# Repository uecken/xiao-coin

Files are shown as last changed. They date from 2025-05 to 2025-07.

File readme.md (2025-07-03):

# XIAO-Coin で始めるIoT開発

詳細ガイドブック：

📖 **[XIAO-Coin ガイドブック](xiao_coin_ebook.md)**

電源スイッチの代替は下記などをご利用ください。

 - 小型スライドスイッチ 1回路2接点 SS12D01G4
https://akizukidenshi.com/catalog/g/g112723/

- スライドスイッチ 1回路2接点 基板用 横向き
https://akizukidenshi.com/catalog/g/g115704/

---

JLCPCBで発注する際は全て通常設定です。
Castellated HolesをYesにすると綺麗にカットしてもらえますが、エッジでしか使えないようなのと費用が嵩むためNoとします。
また、今回は基板の内枠を切り取っているため恐らく使えません。



**販売サイト**: [スイッチサイエンス](https://www.switch-science.com/products/10032)

**GitHub**: [https://github.com/uecken/xiao-coin](https://github.com/uecken/xiao-coin)

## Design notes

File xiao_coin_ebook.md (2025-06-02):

---
pdf-engine: xelatex
CJKmainfont: "Noto Serif CJK JP"
papersize: b5paper
geometry: 
  - paper=b5paper
  - margin=2cm
  - paperwidth=176mm
  - paperheight=250mm
top-level-division: chapter #見出し毎に改ページ
numbersections: false
figureTitle: ""
tableTitle: ""
listingTitle: ""
figPrefix: ""
eqnPrefix: ""
tblPrefix: ""
lstPrefix: ""
header-includes:
  - \usepackage{caption}
  - \captionsetup{labelformat=empty}
  - \captionsetup[figure]{labelformat=empty}
---

<div style="text-align: center; page-break-after: always;">

<br><br>

::: {=latex}
\centering
\Huge \textbf{XIAO-Coinで始めるIoT}
\vspace{4cm}
:::

<br><br>

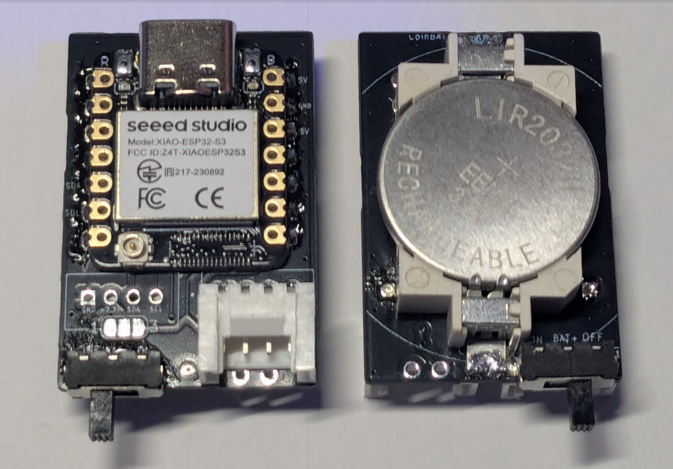
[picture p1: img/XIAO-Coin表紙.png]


<br><br>

::: {=latex}
\centering
\Large \textbf{やわらからじお}

\normalsize
\raggedright
:::

</div>

::: {=latex}
\newpage
:::

------------------------------------------------------------------------

目次
----

1.  [はじめに](#はじめに)
2.  [XIAO-Coinについて](#xiao-coinについて)
3.  [部品とコスト](#部品とコスト)
4.  [組み立て手順](#組み立て手順)
5.  [開発環境の構築](#開発環境の構築)
6.  [センサー接続とプログラミング](#センサー接続とプログラミング)
7.  [応用例とプロジェクト](#応用例とプロジェクト)
8.  [トラブルシューティング](#トラブルシューティング)
9.  [接続図とPCB](#接続図とPCB)
10. [参考資料](#参考資料)

はじめに
--------

本書は、XIAO-Coinを使用した小型充電式無線マイコン、並びにMicroPythonによる簡易なプログラミング解説するガイドブックです。

### 対象読者

-   電子工作初心者ー中級者
-   小型デバイスでのプロトタイピングを行いたい方

### 本書で学べること

-   XIAO-Coinの組み立て
-   MicroPythonによるプログラミング -各種センサーの活用方法

#### 注意点

  - **CR2032電池は使用できません** 
  - **一般的なリチウム電池は使用できません** 
  - **LIR2032/2450専用です**（リチウムイオンコイン電池のみ） 
  - **半田付けに慣れている必要があります**

::: {=latex}
\newpage
:::

XIAO-Coinについて
---------------------

### 概要

XIAO-Coinは、リチウムイオン充電機能のあるSeeed Studio製XIAOとリチウムイオンコイン電池を組み合わせた、小型（38mm x 28mm）の無線マイコンボードです。

オンラインで基板セットを販売しています。GitHubでKiCADファイルを公開していますので、気に入った方は沢山創ったり、カスタマイズして是非ご利用ください。

**スイッチサイエンス販売サイト**: <https://www.switch-science.com/products/10032>

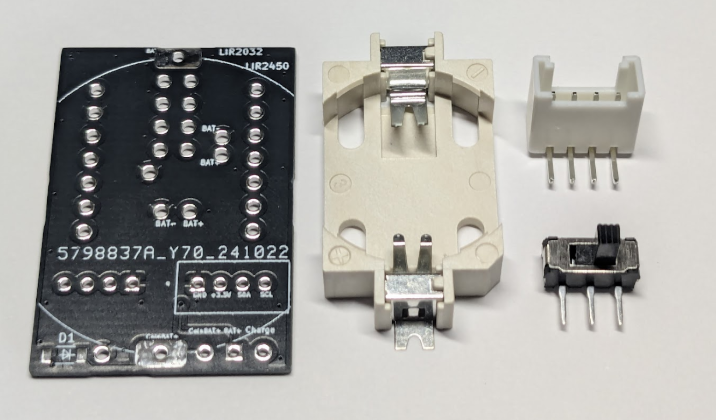
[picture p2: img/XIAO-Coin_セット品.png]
XIAO-Coin_セット品


### 特徴

-   XIAOの小ささとLipo充電端子を生かしたコインホルダー一体型無線マイコン
-   Grove端子でI2Cセンサ接続可能
-   充電機能内蔵のため各種コイン電池に対応：45mAh〜120mAh（2032〜2450サイズ）

::: {=latex}
\newpage
:::

必要部品とコスト
----------------

### 必要部品一覧（BOM）

- XIAOの単価はC3が最も安く、630円/個で試作できるため各種センサの動作評価に向いています。
- これだけ安ければ動作したセンサとセットでそのままにしておけるので、毎回ソフトやセンサを付け替える必要が無いのが便利です。

| 名称 | 価格 | 販売先 | 備考 |
|---|---|---|---|
| XIAO ESP32 C3/C6/S3 | 630円〜810円 | Seeed | 10個購入時の値段  |
| ボタン電池基板取付用ホルダー CH29-2032LF | 50円 | 秋月電子 |
| スライドスイッチ MK-12D13G4-B | 10円 | LCSC | 
| Groveコネクター L型 スルーホール | 15円 | 秋月電子 | 

電源スイッチは背丈の小さいものを採用していますが、秋月電子で代替できる部品は下記です。
 - 小型スライドスイッチ 1回路2接点 SS12D01G4
https://akizukidenshi.com/catalog/g/g112723/
- スライドスイッチ 1回路2接点 基板用 横向き
https://akizukidenshi.com/catalog/g/g115704/

### XIAO各種モデルの単価（Seeed社から10個購入時）

| モデル | 単価（USD） | 単価（円）* | 特徴 |
|---|---|---|---|
| XIAO ESP32 C3 | $4.20 | 630円 | 最安価、WiFi/Bluetooth対応 |
| XIAO ESP32 C6 | $4.90 | 735円 | WiFi 6対応、Thread/Zigbee対応 |
| XIAO ESP32 S3 | $5.40 | 810円 | カメラ対応、AI機能強化 |

*為替レート: 1USD = 150円で計算

### 推奨電池

EEMB LIR2032H 充電式バッテリー - 電圧: 3.7V - 容量: 70mAh - 価格:
¥1,309

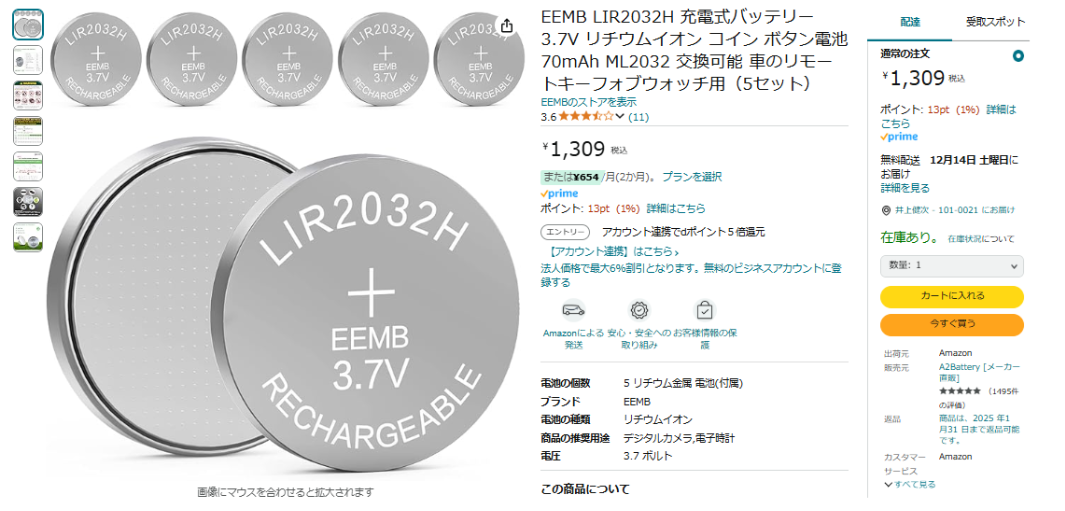
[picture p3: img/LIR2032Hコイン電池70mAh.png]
LIR2032H電池


::: {=latex}
\newpage
:::

組み立て手順
------------

## 部品のハンダ付け手順

1. 基板にXIAOを半田付け
2. 裏面の充電端子をホール半田付け
3. 電源スイッチを半田付け
4. Grove端子を半田付け
5. バッテリーホルダーを半田付け

注: 先にバッテリーホルダーを付けると、XIAOの充電端子を半田付けできないので注意。
次ページで写真付きで説明します。

## XIAOと基板の半田付け
  - XIAOの片側の端子をピン固定し、反対側の端子を半田付けする。

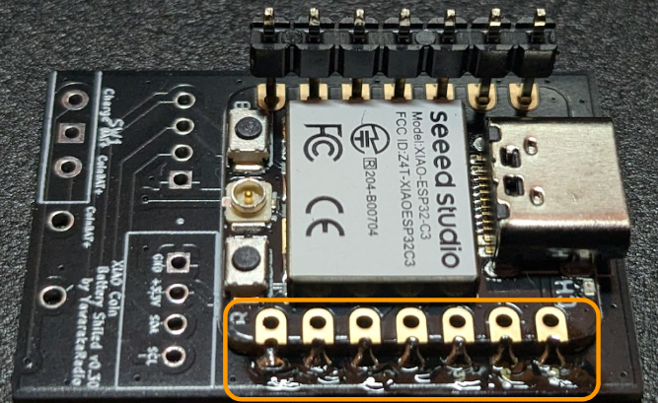
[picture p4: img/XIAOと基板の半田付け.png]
XIAOと基板の半田付け


## XIAOのはんだ付け
  - 反対側のピンを外し、はんだ付けする。

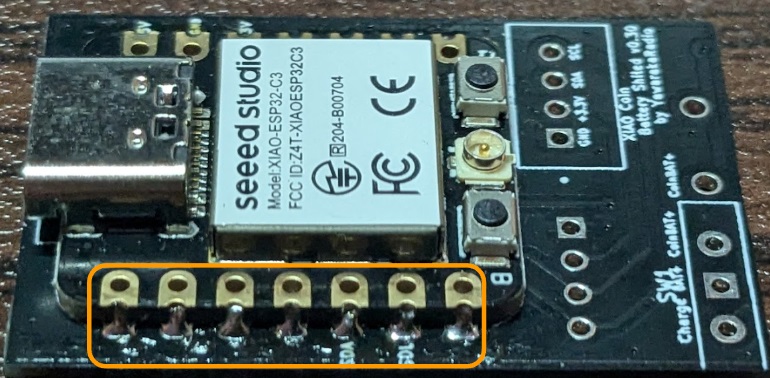
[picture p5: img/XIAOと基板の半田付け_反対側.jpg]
XIAOと基板の半田付け_反対側


::: {=latex}
\newpage
:::

## 充電端子のホール半田付け
  - 基板裏面の充電端子(BAT+、BAT-)をスルーホール越しに半田付けする。（ホール半田付け）
  - 2025年5月から基板をカットして半田付けしやすくしています。

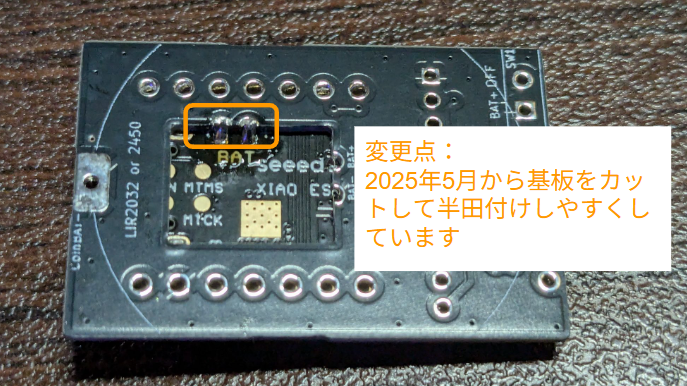
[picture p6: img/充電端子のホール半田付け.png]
充電端子のホール半田付け


## 充電端子のショート確認
  - BAT+とBAT-がショートしていない事を念のため確認する。

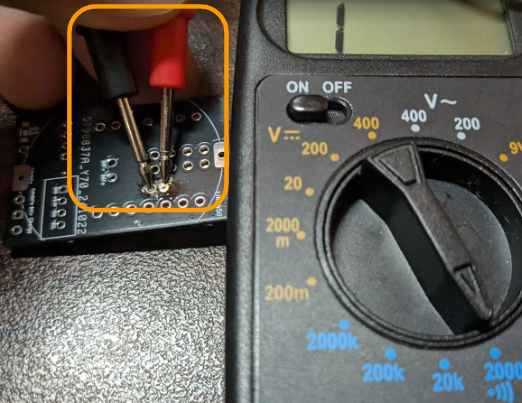
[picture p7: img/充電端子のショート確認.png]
充電端子のショート確認


## 電圧確認
  - USBから電源供給し、充電端子間(BAT+とBAT-)で4.1～4.2V程度の電圧があることを確認する。

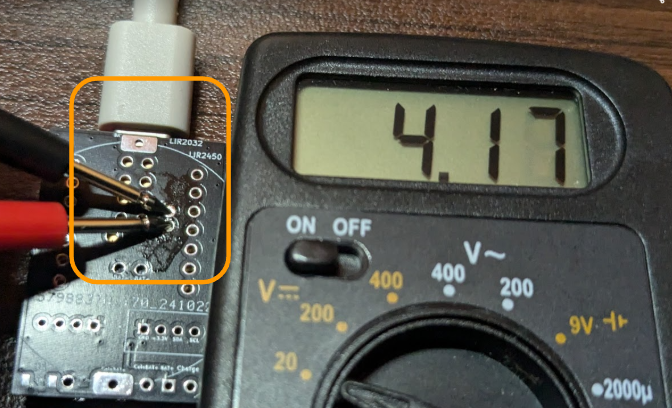
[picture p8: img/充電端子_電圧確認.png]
充電端子_電圧確認


::: {=latex}
\newpage
:::

## 電源スイッチとGroveコネクタの半田付け

- 電源端子とGrove端子のピンを切り1mm程度とする。
- 電源端子→Grove端子の順に半田付けする（低背部品の順に半田付けする）。
- ピンが長いとバッテリーホルダーが浮いてしまうため、適切な長さで且つ半田が隆起しないよう少量とする。

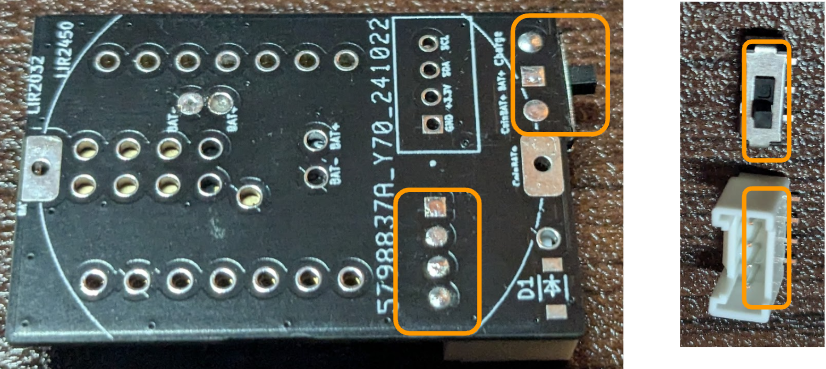
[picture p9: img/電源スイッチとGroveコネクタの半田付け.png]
電源スイッチとGroveコネクタの半田付け


## バッテリーホルダーの半田付け
- バッテリーホルダーを半田付けする。
**バッテリー端子の＋/－をしっかり確認し、＋/－端子を間違えないに半田付けする**。

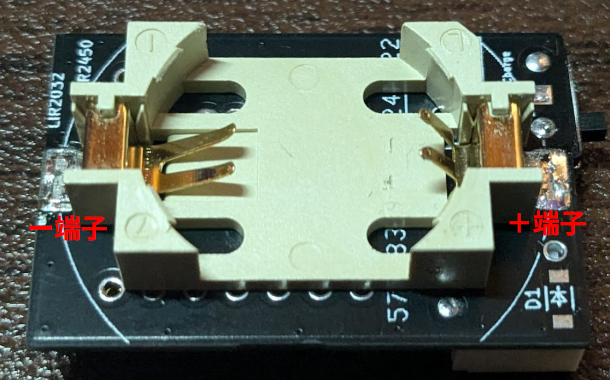
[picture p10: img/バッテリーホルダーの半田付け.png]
バッテリーホルダーの半田付け


::: {=latex}
\newpage
:::

## 電圧確認
- 電源スイッチを中央側に切り替える事でXIAOとバッテリーが通電する。
- バッテリー端子の＋端子と－端子間で電圧が4.1-4.2V程度ある事を確認する。

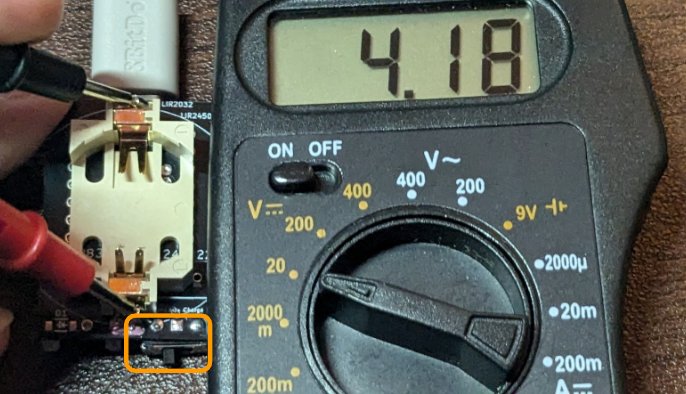
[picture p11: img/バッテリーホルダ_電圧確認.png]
バッテリーホルダ_電圧確認


## 電池の装着

- コイン電池の＋/－がショートしないよう気を付けて装着。

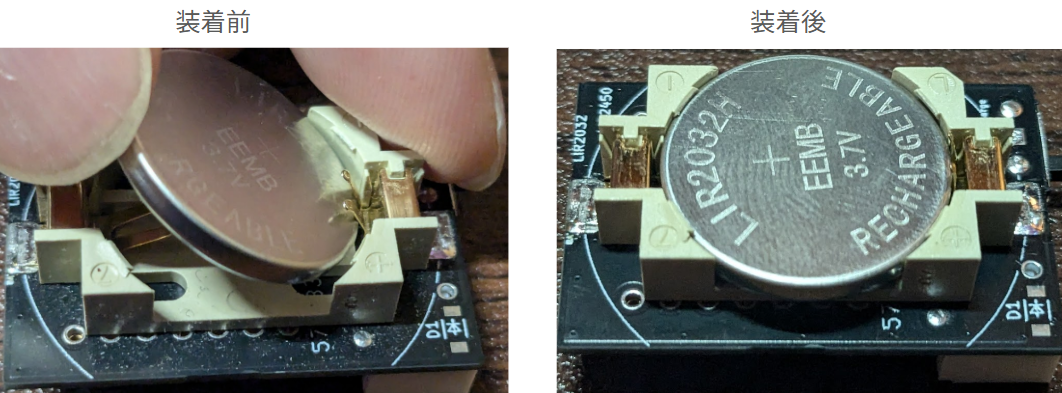
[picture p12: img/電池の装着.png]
電池の装着


## 完成品

<div style="text-align: center;">

完成！

USB接続し、 __スライドスイッチを中央側__ にすると充電され、充電中はCHG LEDが点滅します

好きなセンサを接続しましょう！

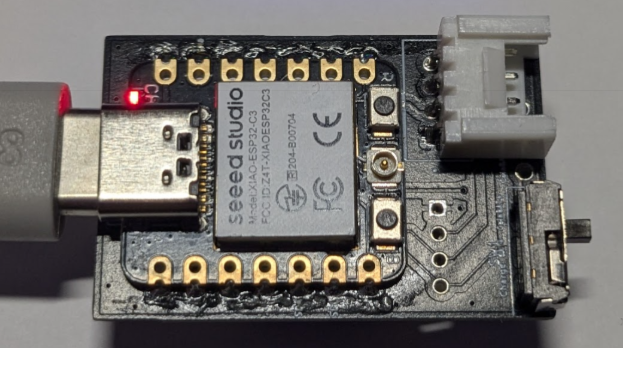
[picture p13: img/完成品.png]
完成品


</div>

::: {=latex}
\newpage
:::

開発環境の構築
--------------

XIAOは様々な種類がありますが、XIAO-ESP32系を利用した方法を記載します。

### Thonnyのインストールと設定

#### 1. Thonnyのインストール

1.  [Thonny公式サイト](https://thonny.org/) https://thonny.org/ からダウンロードし、インストールする。

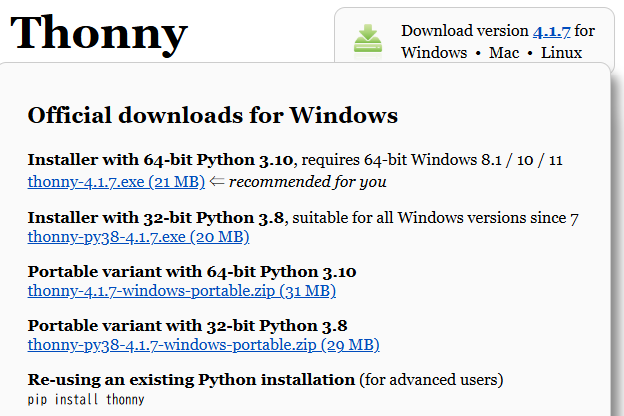
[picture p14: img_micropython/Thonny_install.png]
Thonnyのダウンロード


#### 2. MicroPythonファームウェアの書き込み

下記6ステップを順に行ってください。

-   Thonnyメニュー「Tools」→「Options」
-   「MicroPython(ESP32)」を選択
-   「Install or update MicroPython(esptool)」を選択

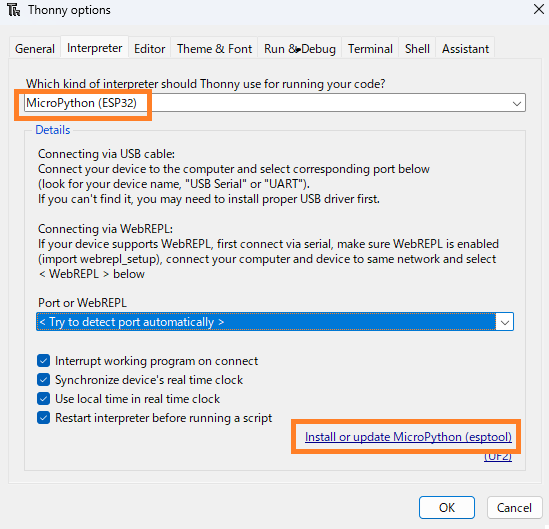
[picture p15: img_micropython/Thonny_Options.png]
Thonny設定画面


-   XIAO ESP32のBootボタンを押しながらUSB接続
    (ブートモードにする必要があります。)
-   適切なCOMポートを選択(USB/JTAGとついているものを選びます)
-   ESP32用ファームウェアを選択してInstall

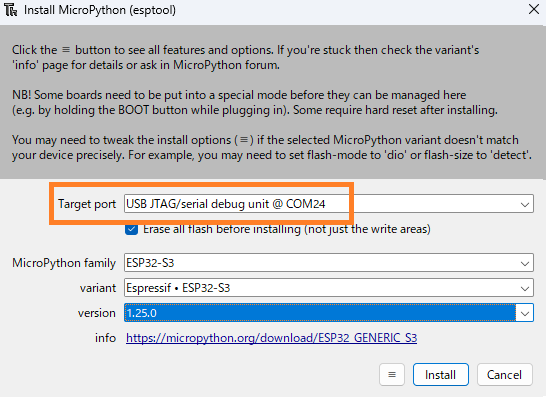
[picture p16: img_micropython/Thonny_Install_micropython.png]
ファームウェア書き込み


::: {=latex}
\newpage
:::

#### 3. ESP32への接続

-   XIAO ESP32のリセットボタンを押すかUSB再接続した後,
    Thonny右下の接続先を適切なCOMポートに変更します
-   「MicroPython(ESP32)」と表示されれば接続成功です

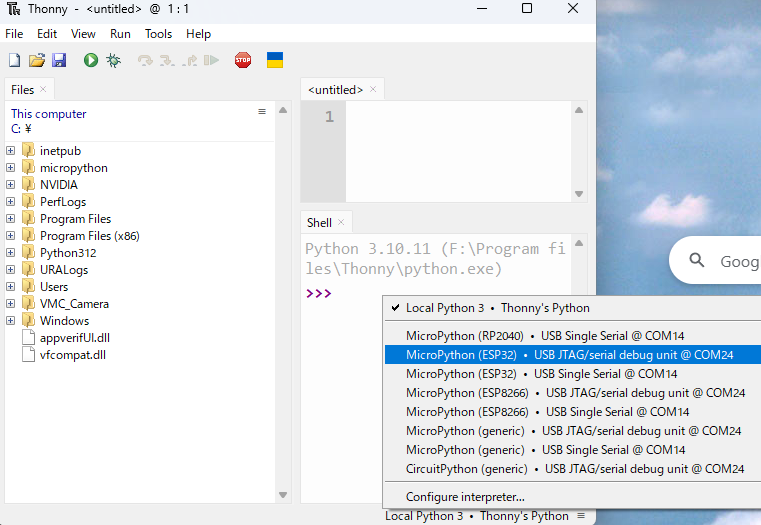
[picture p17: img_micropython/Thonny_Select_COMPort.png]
COMポート選択


#### 4. ファイルのアップロード

-   「View」→「Files」でファイルツリーを表示

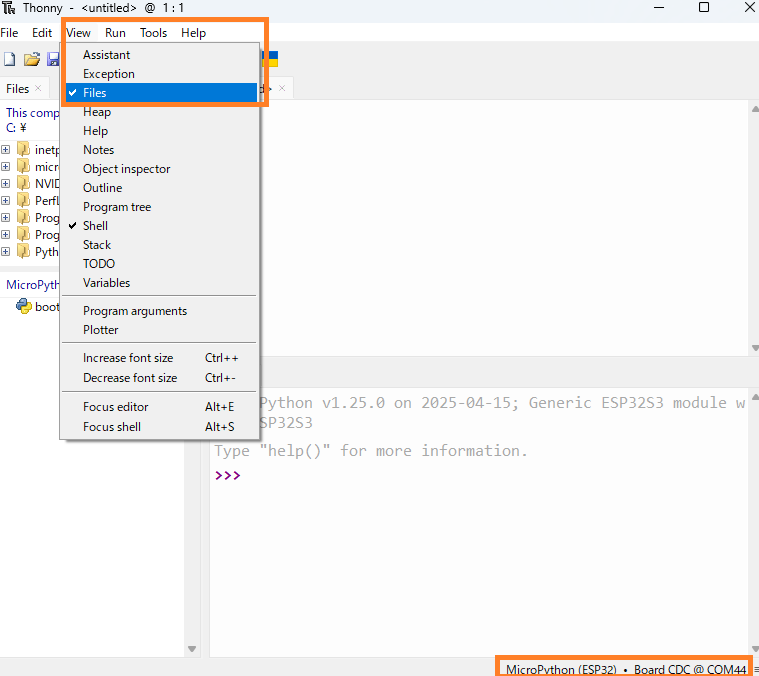
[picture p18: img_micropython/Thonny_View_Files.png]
ファイルビュー


-   micropythonプロジェクトファイルをESP32にアップロード
    -   Githubのリポジトリからmicropythonフォルダをダウンロードし、Cドライブ直下に格納してからアップロードしてください
        https://github.com/uecken/xiao-coin

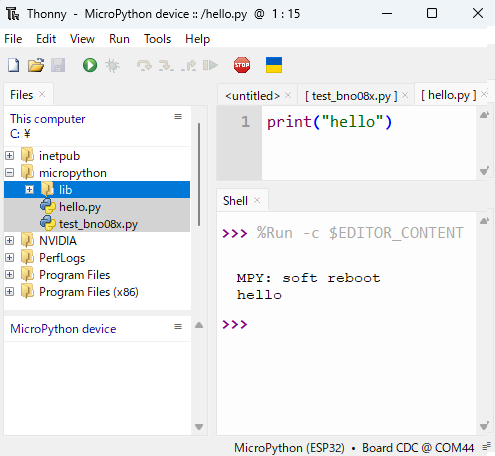
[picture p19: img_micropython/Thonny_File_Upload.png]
ファイルアップロード


::: {=latex}
\newpage
:::

#### ５．テストプログラムの実行

-   再生ボタンを押し、Helloと表示されれば動作しています。

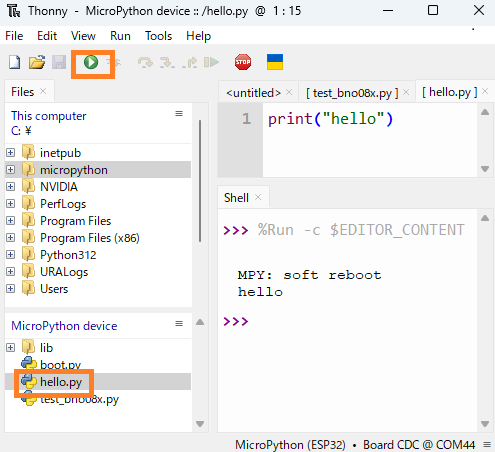
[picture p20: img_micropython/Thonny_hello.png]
Hello.pyの実行


::: {=latex}
\newpage
:::

センサー接続とプログラミング
----------------------------

### BNO085 IMUセンサーの使用

#### センサーの調達

-   BNO085は AliExpressから購入すると安いです。

-   但しGroveコネクタを使う場合、3.3V--GND、SDA--SDLピンをそれぞれ入れ替える必要があるので注意してください。

-   URL: https://ja.aliexpress.com/item/1005005902501032.html

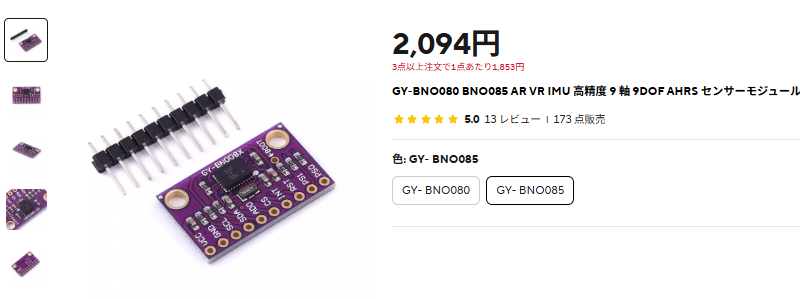
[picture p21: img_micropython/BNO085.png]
BNO085


#### 配線方法

- 参考までに、Aliexpressのモジュールのピン配置、正規のGroveコネクタのピン配置を参考として示します。正規のGroveコネクタのピン配置に合わせるために、3.3V--GND、SDA--SDLピンをそれぞれ入れ替える必要があります

- 一般的にI2CはSDAとSCLにプルアップ抵抗が必要です。通信が安定しない場合、3.3VとSDA、3.3VとSCLを繋ぐように4.7kΩの抵抗を接続して下さい。

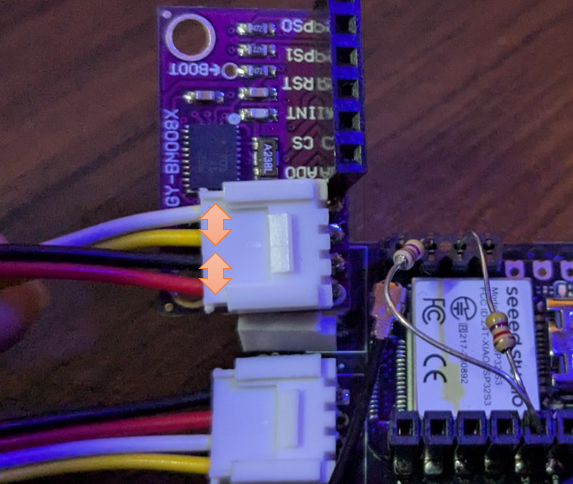
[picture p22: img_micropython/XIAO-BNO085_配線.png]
XIAO-BNO085_配線


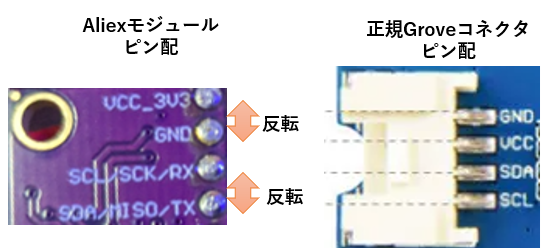
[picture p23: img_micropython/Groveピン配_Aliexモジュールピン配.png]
Groveピン配置とAliexモジュールピン配置


::: {=latex}
\newpage
:::

#### サンプルプログラム

- サンプルプログラムは下記に格納しています。
- https://github.com/uecken/xiao-coin/blob/main/micropython/test\_bno08x\_simple.py

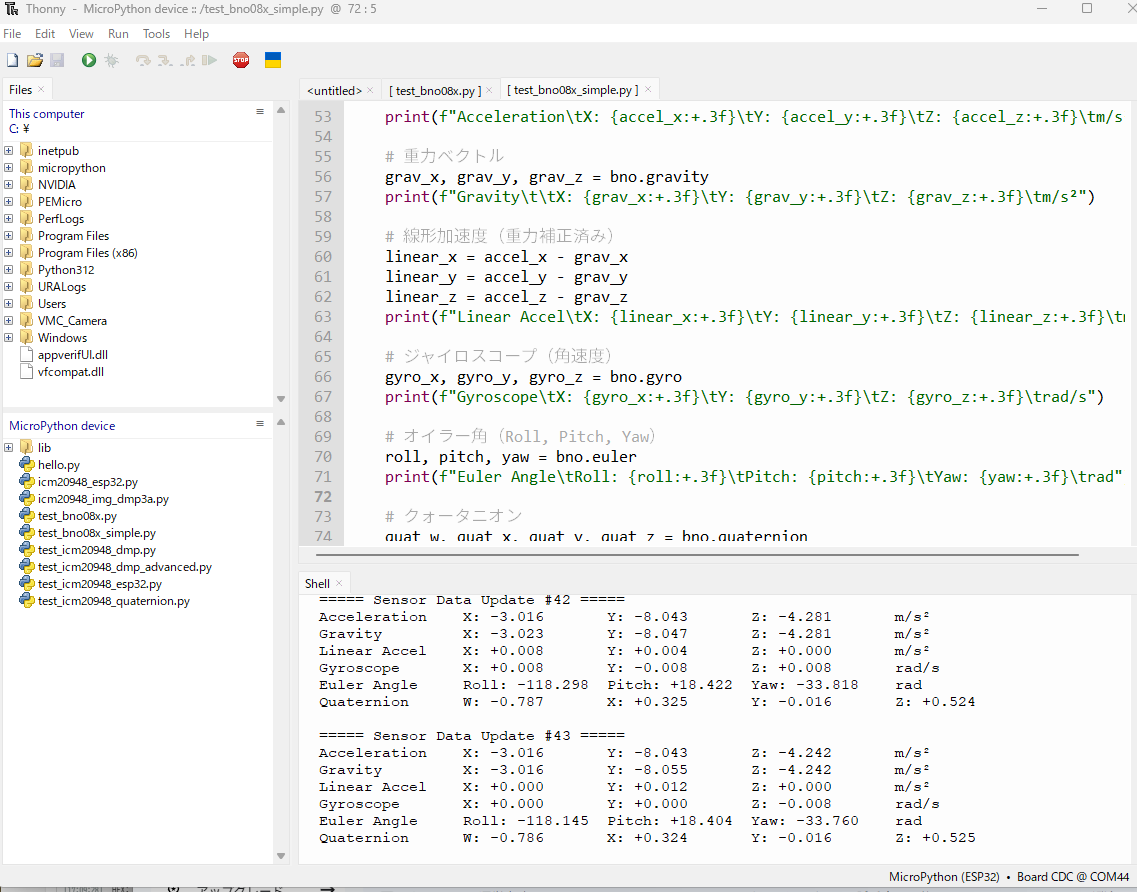
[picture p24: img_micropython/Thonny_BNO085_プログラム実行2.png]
Thonny_BNO085_プログラム実行結果


    ===== Sensor Data Update #42 =====
    Acceleration    X: -3.016   Y: -8.043   Z: -4.281   m/s²
    Gravity     X: -3.023   Y: -8.047   Z: -4.281   m/s²
    Linear Accel    X: +0.008   Y: +0.004   Z: +0.000   m/s²
    Gyroscope   X: +0.008   Y: -0.008   Z: +0.008   rad/s
    Euler Angle Roll: -118.298  Pitch: +18.422  Yaw: -33.818    rad
    Quaternion  W: -0.787   X: +0.325   Y: -0.016   Z: +0.524

<br>

参考までに、重力加速度を除いたLinear
Accel（線形加速度）が取れるので正しく使えばある程度の相対位置測位に利用できます。

-   **意味**: 重力を除いた純粋な加速度（Acceleration - Gravity）
-   **単位**: m/s²
-   **値の解釈**:
    -   X: +0.008 m/s² → ほぼゼロ（静止状態）
    -   Y: +0.004 m/s² → ほぼゼロ（静止状態）
    -   Z: +0.000 m/s² → 完全にゼロ（静止状態）
-   **用途**: 物体の実際の動きの検出、歩数計、振動検知

::: {=latex}
\newpage
:::

接続図とPCB
-----------

-   ソルダージャンパーは通常3.3Vに繋がっていますが、カットして5V側に半田付けする事でGroveの電源を5Vで駆動出来ます。
-   中央を四角にカットしているので、XIAOの裏面の充電端子と半田付けしやすくなっています。
-   KiCADファイルを公開しているので、XIAO
    Coinを沢山つかったり、カスタマイズする際にご利用下さい。PR頂けると嬉しいです。
    -   KiCAD:
        https://github.com/uecken/xiao-coin/tree/main/XIAO\_ButtonBatteryPCB\_Public
-   GerverデータをJLCPCBにアップロードして発注すれば5枚3$で約一週間で到着します。
    - [Gerber URL](https://github.com/uecken/xiao-coin/blob/main/XIAO_ButtonBatteryPCB_Pulic/production/XIAO_ButtonBatteryPCB_v0.4.zip)

XIAO_PCB

XIAO_接続図

::: {=latex}
\newpage
:::

### トラブルシューティング

-   **充電されない**: 電池の極性、充電端子の半田付けを確認してください
-   **電圧が出ない**: ショートの有無、スイッチの位置を確認してください
-   **I2C通信エラー**: プルアップ抵抗の追加や配線を確認してください

### 参考資料

-   **GitHub**: https://github.com/uecken/xiao-coin/tree/main

### 最新の更新内容（2025/5/23）

1.  XIAOと基板の充電端子を半田付けしやすくするため中央部分をカット（Castellated
    Hole化）
2.  Grove端子の電源をSolder Jumperで3.3V/5V選択可能に
3.  Grove端子を表面にも追加可能に

連絡先・サポート
----------------

**やわらからじお** 
- X: @uecken
- Email: <yawaraka.radio@gmail.com>

::: {=latex}
\newpage
:::

::: {=latex}
\vspace*{\fill}
\centering
:::



::: {=latex}
\vspace*{\fill}
\centering
:::

**© 2025 やわらからじお - XIAO-Coinで始めるIoT**

::: {=latex}
\normalsize
\raggedright
:::

</div>

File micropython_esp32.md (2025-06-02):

# MicroPython ESP32 開発ガイド

## 目次
1. [開発環境の準備](#開発環境の準備)
2. [Thonnyの設定](#thonnyの設定)
3. [BNO085センサーの使用方法](#bno085センサーの使用方法)
4. [実践的なプロジェクト例](#実践的なプロジェクト例)

## 開発環境の準備

### 必要なもの
- ESP32開発ボード
- BNO085センサーモジュール
- ジャンパーワイヤー
- USB-Cケーブル（ESP32による）
- PC（Windows/Mac/Linux）

### Thonnyのインストール

1. [Thonny公式サイト](https://thonny.org/)からダウンロード
2. インストーラーを実行してセットアップ

Thonnyダウンロードページ

## Thonnyの設定

### MicroPythonファームウェアの書き込み

1. Thonnyメニューから「Tools」→「Options」を選択
2. 「Interpreter」タブを開く
3. 上部のドロップダウンメニューで「MicroPython (ESP32)」を選択
4. 右下の「Install or update MicroPython (esptool)」ボタンをクリック

Thonny_Options

5. **重要**: XIAO ESP32のBootボタンを押しながらUSBケーブルを接続する
   - これによりESP32がダウンロードモードに入ります
6. ポート選択画面で「USB JTAG...」と表示されているCOMポートを選択

7. ファームウェア選択画面で以下を設定：
   - **Target port**: 検出されたCOMポートが表示されていることを確認
   - **MicroPython family**: 使用するESP32に応じて選択
     - XIAO ESP32S3の場合: 「ESP32-S3」を選択
     - XIAO ESP32C3の場合: 「ESP32-C3」を選択
     - XIAO ESP32C6の場合: 「ESP32-C6」を選択
   - **Variant**: 通常は「Espressif ESP32-S3」など標準版を選択
   - **Version**: 最新の安定版を選択（通常は最上位に表示）

8. 「Install」ボタンをクリックしてファームウェアの書き込みを開始
   - 書き込み中は進行状況が表示されます
   - 完了まで数分かかる場合があります

ファームウェア書き込み

9. 書き込み完了後、「Close」ボタンでダイアログを閉じる

**注意事項**:
- 書き込み中はUSBケーブルを抜かないでください
- エラーが発生した場合は、ESP32を再度ダウンロードモードにして再試行してください
- 初回書き込み時は既存のプログラムが消去されます

### ESP32への接続

1. XIAO EPS32のリセットボタンを押すか、USBケーブルを差し直す。
2. Thonnyで右下の"Local Python3"と表示されている個所をクリックし、適切なCOMポートを選択<br>
Thonny_Select_COMPort

3. 接続確認 と ファイルアップロード
MicroPython(ESP32)と表示されていれば接続出来ている。

ファイルツリーが表示されていない場合、 View > File にて、ファイルツリーを表示する。
Thonny_View_Files

Githubのリポジトリからmicropythonフォルダをダウンロードし、Cドライブ直下に格納する。
https://github.com/uecken/xiao-coin

micropythonフォルダ内のファイルを選択し、アップロードする。
Thonny_File_Upload

3. hellp.pyの動作確認
　hello.pyをダブルクリックし、再生ボタンを押す。
  コンソールに "hello" と表示されれば正常動作している。


## IMUセンサBNO085

1. 調達

* BNO085は AliExpressから購入すると安いです。
* 但しGroveコネクタを使う場合、3.3V⇔GND、SDA⇔SDLピンをそれぞれ入れ替える必要があるので注意してください。
https://ja.aliexpress.com/item/1005005902501032.html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



2. 配線

- Groveコネクタを図のように配置し、3.3V⇔GND、SDA⇔SDLピンをそれぞれ入れ替えていることに注意してください。
- 一般的にI2CはSDAとSCLにプルアップ抵抗が必要です。通信が安定しない場合、3.3VとSDA、3.3VとSCLを繋ぐように4.7kΩの抵抗を接続して下さい。




3. I2CのSDAとSDLピン合わせ

I2Cのピン配置は利用するESP32のピン配置によって異なります。
```
I2C1_SDA = Pin(5) #XIAO-ESP32C6:22,  C3:6, S3:5, M5StickC:0
I2C1_SCL = Pin(6) #XIAO-ESP32C6:23,  C6:7, S3:6, M5StickC:26
```

test_bno08x.pyを選択し、実行する。
Thonny_プログラム実行

参考までに、Ceva BNO085は高精度IMUであり多くのロボットやゲーム器に採用されている。
Euler AngleのX,Yは水平角度のずれを示すので、水平器等に応用ができる。

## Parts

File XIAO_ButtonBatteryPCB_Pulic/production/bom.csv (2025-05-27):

Designator | Footprint | Quantity | Value | LCSC Part #
C1 | C_Radial_D6.3mm_H7.0mm_P2.50mm | 1 | C
C4 | 2450_MYOUNG BS-24-B4AK014 | 1 | C
J1, J2 | SEEED_110990030 | 2 | 110990030__Grove
R1, R2 | 0603 | 2 | 4.7k
SW1 | SW_Slide-03_Wuerth-WS-SLTV_10x2.5x6.4_P2.54mm | 1 | MK-12D13G4-B
U1 | XIAO_Seeed_ESP32C3_C6_BatteryHolder_v2.1 | 1 | XIAO-ESP32C3_C6

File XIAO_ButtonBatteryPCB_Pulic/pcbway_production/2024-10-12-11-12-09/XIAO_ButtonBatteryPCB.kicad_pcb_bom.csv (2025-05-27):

Designator | Quantity | Value | Footprint | Package | MPN | DNP | Mount_Type | Description | Sim.Device | Sim.Pins | MF | MAXIMUM_PACKAGE_HEIGHT | Price | Check_prices | STANDARD | PARTREV | SnapEDA_Link | MP | Purchase-URL | Description_1 | Availability | MANUFACTURER
C1 | 1 | C | LIR2450_EEMB |  |  |  | tht | Unpolarized capacitor
C2 | 1 | C | 2032_BS-2032-8-3 |  |  |  | smt | Unpolarized capacitor
C3 | 1 | C | 2032_BS-2032-8C |  |  |  | smt | Unpolarized capacitor
C4 | 1 | C | 2450_MYOUNG BS-24-B4AK014 |  |  |  | smt | Unpolarized capacitor
D1 | 1 | RB160M-30 | DIO_RB160M-30 |  |  |  | smt | Diode | D | 1=K 2=A
J1, J2 | 2 | 110990030__Grove | SEEED_110990030 | None |  |  | tht |  |  |  | Seeed Technology | 8.1mm | None | https://www.snapeda.com/parts/110990030/Seeed+Technology+Co.%252C+Ltd/view-part/?ref=eda | Manufacturer Recommendations | A | https://www.snapeda.com/parts/110990030/Seeed+Technology+Co.%252C+Ltd/view-part/?ref=snap | 110990030 | https://www.snapeda.com/api/url_track_click_mouser/?unipart_id=583576&manufacturer=Seeed Technology&part_name=110990030&search_term=None | GROVE 2MM 4PIN VERT CONN 10PCS | In Stock | Seeed Technology
SW1 | 1 | SW_Wuerth_450301014042 | SW_Slide-03_Wuerth-WS-SLTV_10x2.5x6.4_P2.54mm |  |  |  | tht | Switch slide, single pole double throw
U1 | 1 | XIAO-ESP32C3_C6 | XIAO_Seeed_ESP32C3_C6_BatteryHolder_v2 |  |  |  | smt

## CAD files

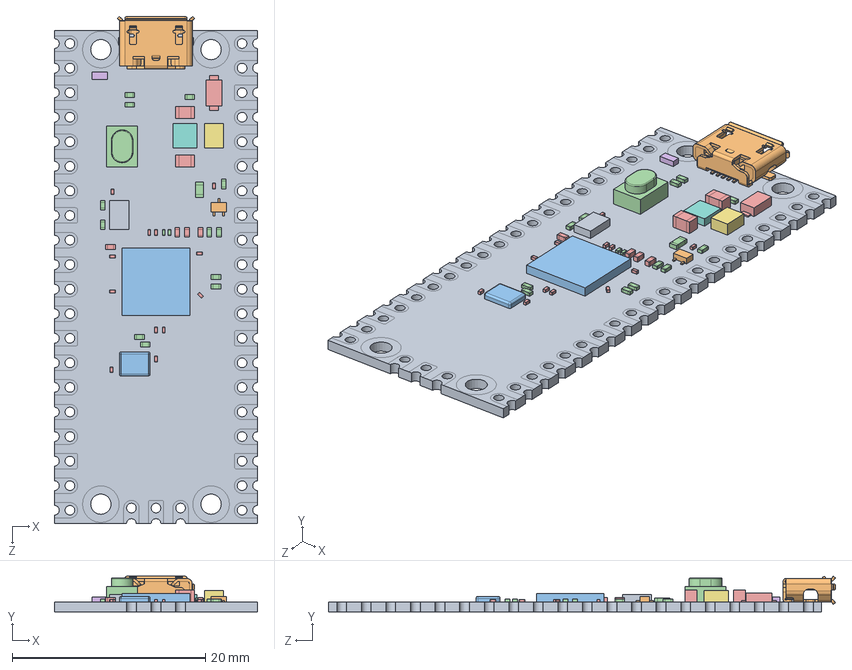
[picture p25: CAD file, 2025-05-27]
XIAO_ButtonBatteryPCB_Pulic/3D/raspberry-pi-pico-r3-1.snapshot.2/Raspberry Pi Pico-R3.SLDASM
21.0 x 3.69 x 52.4 mm
PCB, Raspberry Pi Pico-R3
MicroUSB Port, Raspberry Pi Pico-R3
RP2040 Microcontroller, Raspberry Pi Pico-R3
SW1, Tact Switch, Raspberry Pi Pico-R3
D1, Diode, Schottky, Raspberry Pi Pico-R3
D2, QSME-C194, LED, Raspberry Pi Pico-R3
L1, Inductor, Raspberry Pi Pico-R3
U2, RT6150B-33GQW, Buck Boost Converter, Raspberry Pi Pico-R3
U3, W25Q16JVUXIQ, Serial NOR Flash 16 Mbit, Raspberry Pi Pico-R3
Q1, MOSFET, DMG1012T, Raspberry Pi Pico-R3
X1, X12M000000S096, 12 Mhz Crystal Resonator, Raspberry Pi Pico-R3
SMD Resistor, Configurable, Raspberry Pi Pico-R3 x 15
SMD Capacitor, Configurable, Raspberry Pi Pico-R3 x 18

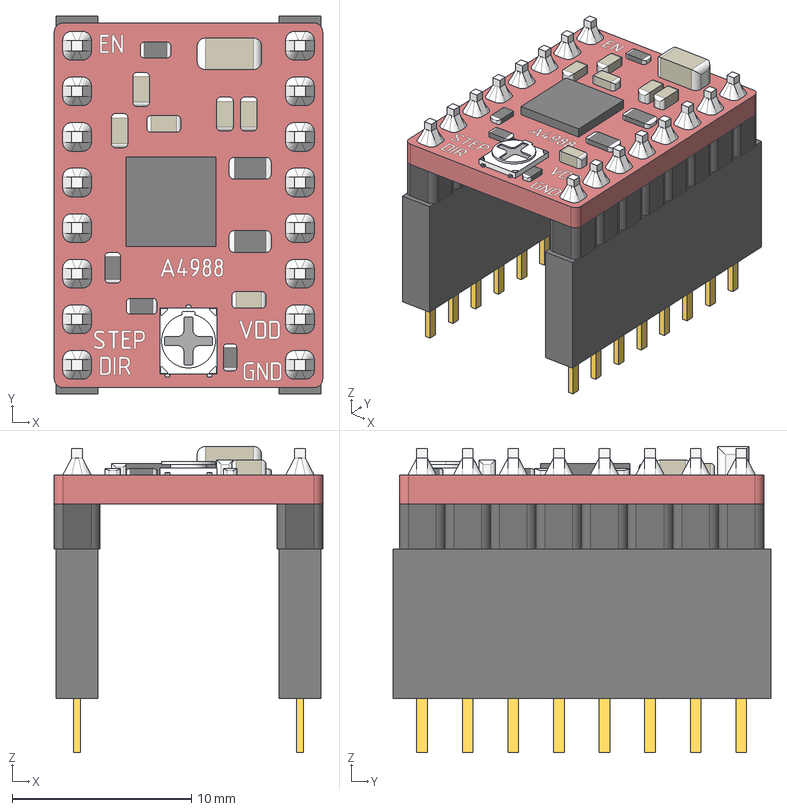
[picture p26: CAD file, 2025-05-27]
XIAO_ButtonBatteryPCB_Pulic/3D/a4988-stepper-driver-with-pins-socketed-1.snapshot.2/A4988-Stepper-Driver-Socketed.stp
15.0 x 21.1 x 17.1 mm

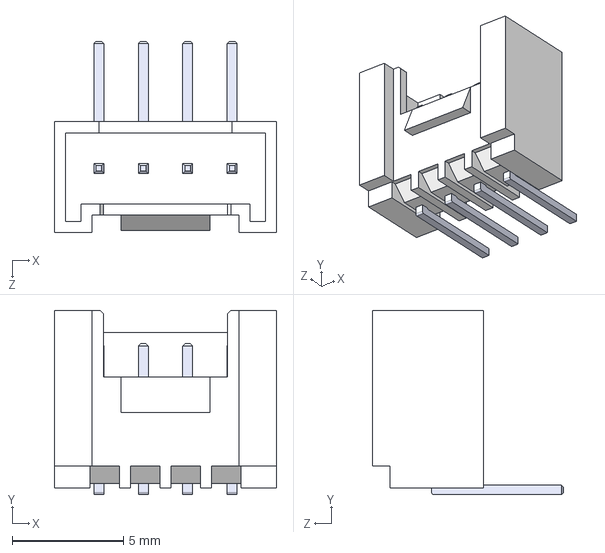
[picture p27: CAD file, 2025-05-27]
XIAO_ButtonBatteryPCB_Pulic/3D/grove-connectors-stand-and-flat-male-plugs-1.snapshot.44/Grove Connector (lying).STEP
10.0 x 8.30 x 8.62 mm

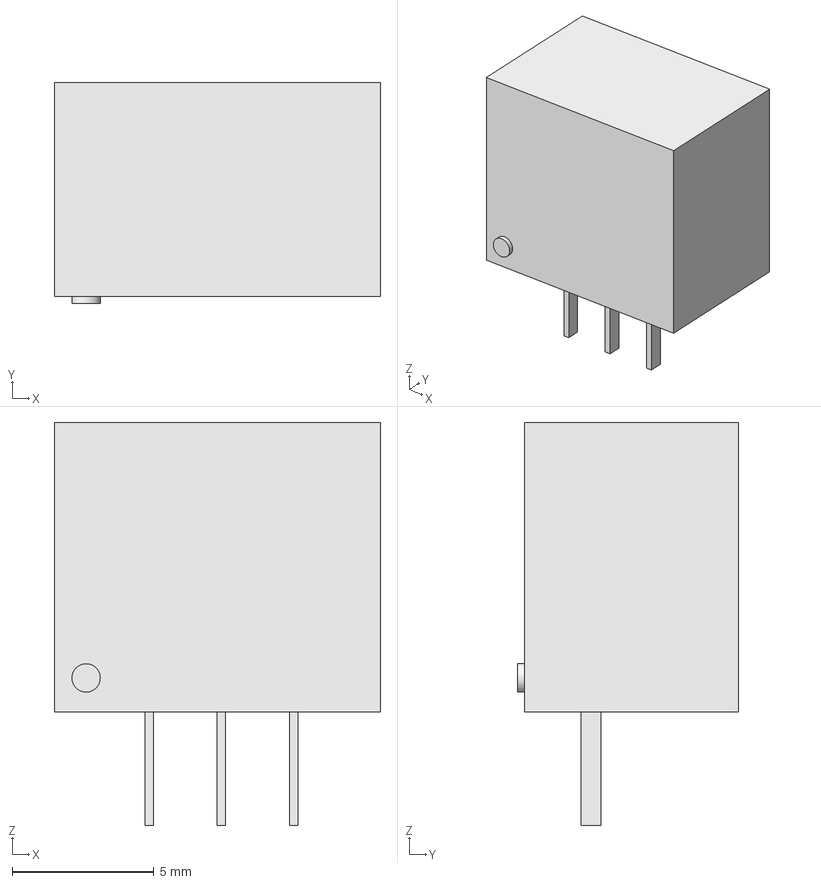
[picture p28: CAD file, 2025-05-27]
XIAO_ButtonBatteryPCB_Pulic/3D/M78AR05-1.step
11.5 x 7.79 x 14.2 mm

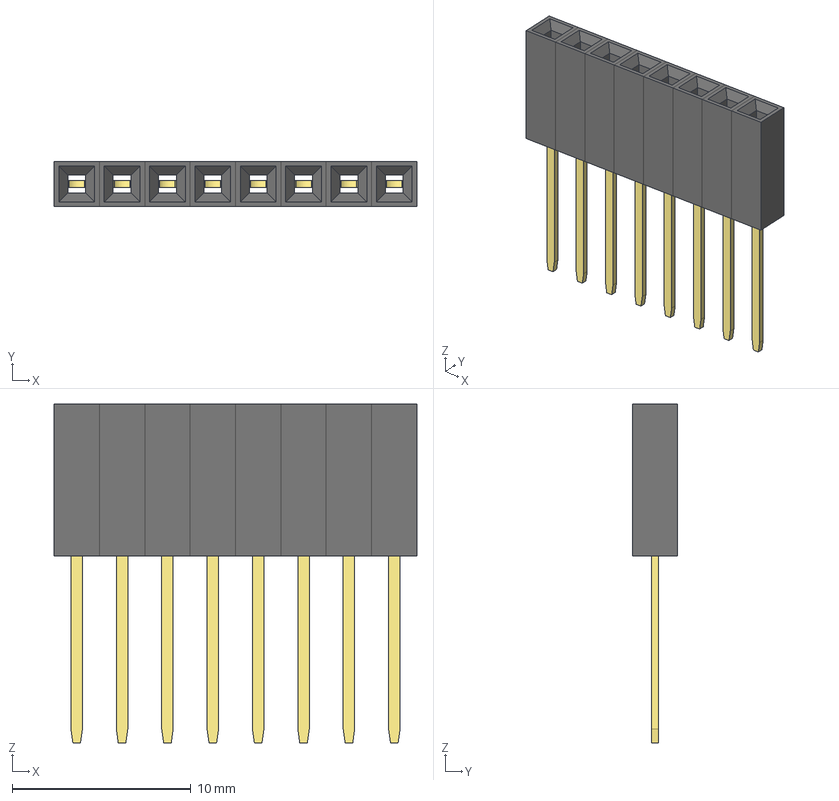
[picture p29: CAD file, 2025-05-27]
XIAO_ButtonBatteryPCB_Pulic/3D/pcb-header-8x1-8-5-mm-stackable-socket/SIL_Socket08_.stp
20.3 x 2.54 x 19.0 mm

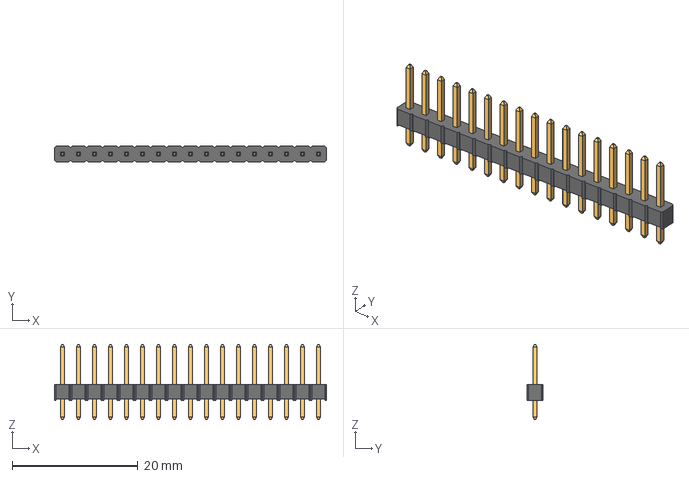
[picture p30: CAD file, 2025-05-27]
XIAO_ButtonBatteryPCB_Pulic/3D/pin-header-male-2-54mm-different-pin-numbers-1.snapshot.2/17-Pin Header - Male - 2.54mm.step
43.2 x 2.54 x 11.9 mm

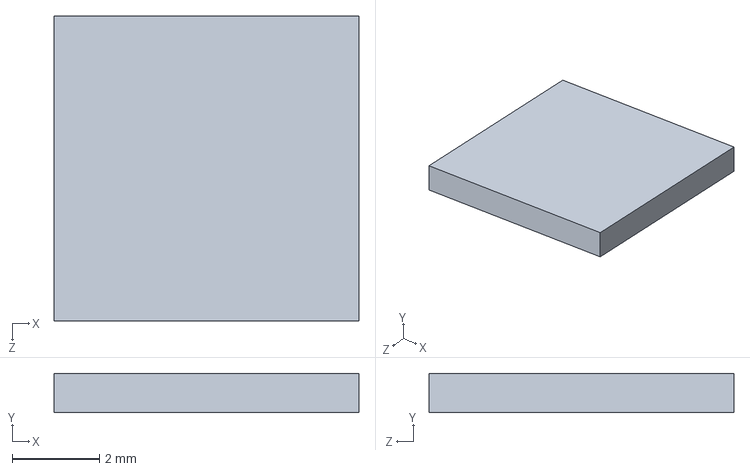
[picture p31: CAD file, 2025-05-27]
XIAO_ButtonBatteryPCB_Pulic/3D/raspberry-pi-pico-r3-1.snapshot.2/RP2040 Microcontroller, Raspberry Pi Pico-R3.SLDPRT
7.00 x 0.9 x 7.00 mm

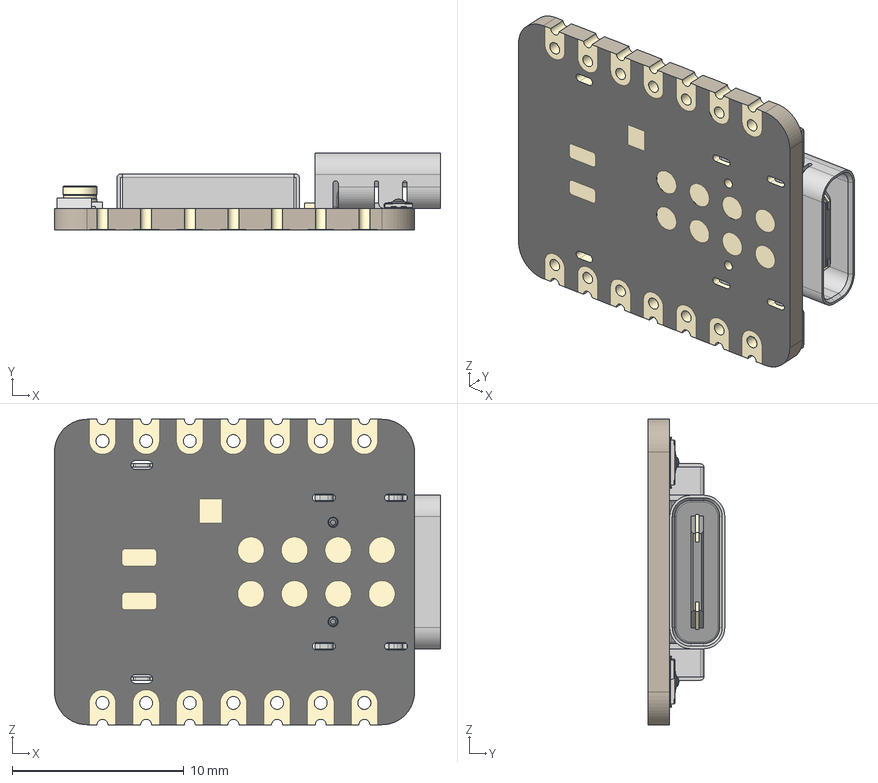
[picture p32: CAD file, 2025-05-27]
XIAO_ButtonBatteryPCB_Pulic/3D/seeed-studio-xiao-esp32-c6-1.snapshot.3/Seeed Studio XIAO ESP32-C6.step
22.5 x 4.46 x 17.8 mm
BOSS-EXTRUDE14_8_
BOSS-EXTRUDE7_4_
BOSS-EXTRUDE7_3_
BOSS-EXTRUDE14_4_
BOSS-EXTRUDE14_2_
BOSS-EXTRUDE14_11_
BOSS-EXTRUDE7_7_
BOSS-EXTRUDE14_9_
BOSS-EXTRUDE14_3_
BOSS-EXTRUDE14_7_
MIRROR2
BOSS-EXTRUDE14_5_
BOSS-EXTRUDE14_12_
BOSS-EXTRUDE7_8_
BOSS-EXTRUDE7_1_
BOSS-EXTRUDE14_10_
BOSS-EXTRUDE7_9_
BOSS-EXTRUDE14_6_
BOSS-EXTRUDE14_1_
BOSS-EXTRUDE7_6_
BOSS-EXTRUDE7_2_
CUT-EXTRUDE5
BOSS-EXTRUDE7_5_
U.FL Connector v1
Shield
SKTAAAE010 x 2
KH5220-A36 (Ceramic Antenna) v2

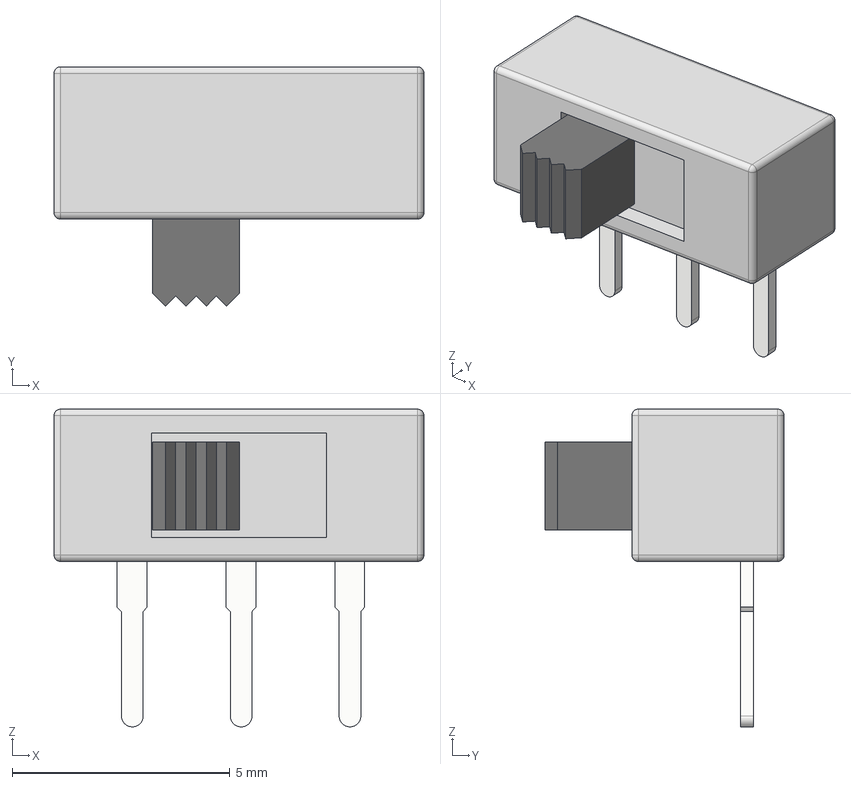
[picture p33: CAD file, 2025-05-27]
XIAO_ButtonBatteryPCB_Pulic/3D/switch-slide-spdt-300ma-6v-mhss1105-1.snapshot.1/SPDT MSHS1105 APEM v2_MK-12D13G4-B.step
8.50 x 5.50 x 7.30 mm
SPDT MSHS1105 APEM v2
SPDT MSHS1105 APEM v003
SPDT MSHS1105 APEM v004
SPDT MSHS1105 APEM v005
SPDT MSHS1105 APEM v006

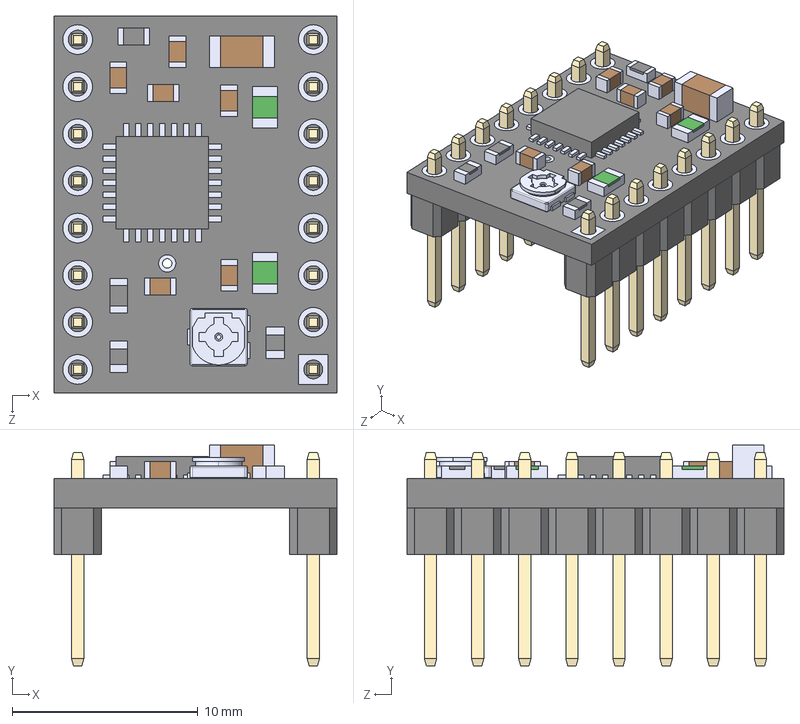
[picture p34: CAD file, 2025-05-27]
XIAO_ButtonBatteryPCB_Pulic/parts/A4988_STEPPER_MOTOR_DRIVER_CARRIER/A4988_STEPPER_MOTOR_DRIVER_CARRIER.step
15.2 x 11.9 x 20.3 mm

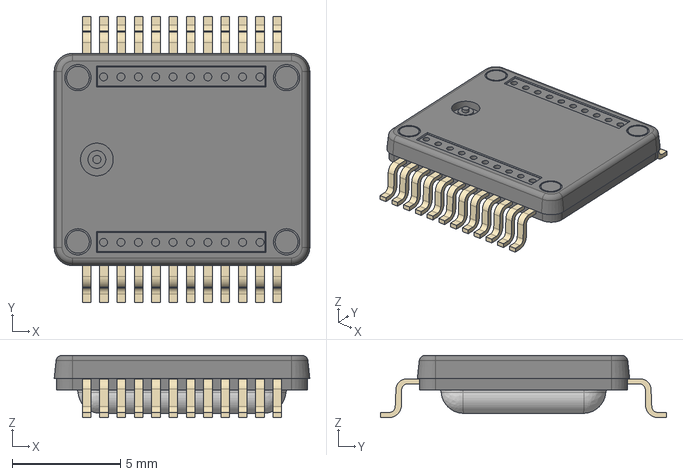
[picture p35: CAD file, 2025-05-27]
XIAO_ButtonBatteryPCB_Pulic/parts/SCH16T-K01-1/3D/SCH16T-K01-1.stp
11.8 x 13.2 x 2.87 mm

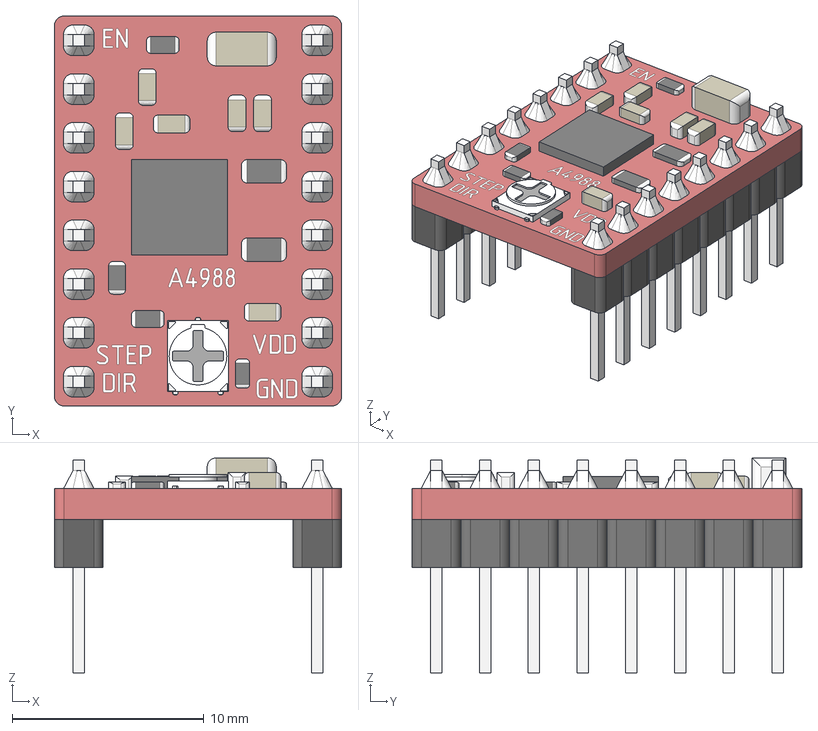
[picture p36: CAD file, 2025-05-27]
XIAO_ButtonBatteryPCB_Pulic/3D/a4988-stepper-driver-with-pins-socketed-1.snapshot.2/A4988-Stepper-Driver-WithPins.stp
15.0 x 20.3 x 11.2 mm

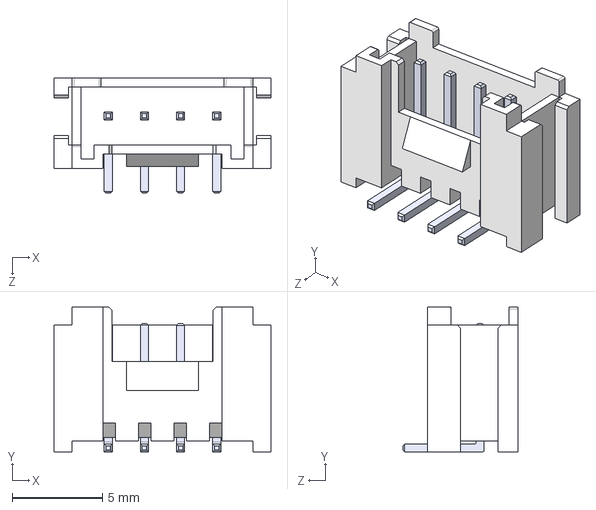
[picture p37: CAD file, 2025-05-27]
XIAO_ButtonBatteryPCB_Pulic/3D/grove-connectors-stand-and-flat-male-plugs-1.snapshot.44/Grove Connector (sit).STEP
12.0 x 8.00 x 6.38 mm

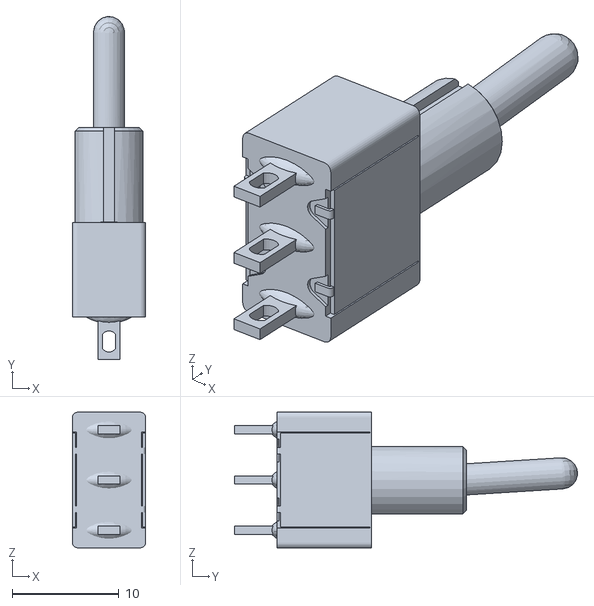
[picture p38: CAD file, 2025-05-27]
XIAO_ButtonBatteryPCB_Pulic/3D/Like_2MS1-T1-B4-M2-Q-E/Like_2MS1-T1-B4-M2-Q-E.stl
6.86 x 32.1 x 12.7

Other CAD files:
XIAO_ButtonBatteryPCB_Pulic/3D/pin-header-male-2-54mm-different-pin-numbers-1.snapshot.2/2-Pin Header - Male - 2.54mm.step
XIAO_ButtonBatteryPCB_Pulic/3D/raspberry-pi-pico-r3-1.snapshot.2/U3, W25Q16JVUXIQ, Serial NOR Flash 16 Mbit, Raspberry Pi Pico-R3.SLDPRT
XIAO_ButtonBatteryPCB_Pulic/3D/switch-slide-spdt-300ma-6v-mhss1105-1.snapshot.1/SPDT MSHS1105 APEM v2.step
XIAO_ButtonBatteryPCB_Pulic/3D/Like_2MS1-T1-B4-M2-Q-E/401692.stp
XIAO_ButtonBatteryPCB_Pulic/3D/grove-connectors-stand-and-flat-male-plugs-1.snapshot.44/Grove Connector (flat).SLDPRT
XIAO_ButtonBatteryPCB_Pulic/3D/grove-connectors-stand-and-flat-male-plugs-1.snapshot.44/Grove Connector (flat).STEP
XIAO_ButtonBatteryPCB_Pulic/3D/grove-connectors-stand-and-flat-male-plugs-1.snapshot.44/Grove Connector (lying).SLDPRT
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

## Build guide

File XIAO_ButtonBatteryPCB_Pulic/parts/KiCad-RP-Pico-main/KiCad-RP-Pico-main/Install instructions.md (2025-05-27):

# Install instructions

## 1. Copy the files locally

Copy the `RP-Pico Libraries` folder wherever you like on your computer.

## 2. Install the Raspberry Pi Pico board schema symbol

Use the `KiCad | Preferences | Manage Symbol Libraries...` command to manage the symbol library:



then select the global tab and click on the folder button:



navigate to the `RP-Pico Libraries` folder, select the `MCU_RaspberryPi_and_Boards.kicad_sym` file and open it:



et voilà, the first step is completed:



You can now close the symbol libraries manager window.

## 3. Install the Raspberry Pi Pico board footprint

You can use a similar approach to add the footprint to the footprint libraries manager, but I've found some issues that I've solved using the footprint editor, so here are the steps I suggest you to follow:

Open the footprint editor



wait for the footprints to load... then use the `File | Add Library` command:



confirm the `Global` choice:



and select the `MCU_RaspberriPi_and_Boards.pretty` folder (yes, the folder represent a footprint library on KiCad):



Now the library is installed on KiCad with the Raspberry Pi Pico footprint (double click on it to see it on the editor pane):



Don't close the windows as the next step start from here.

## 4. Install the Raspberry Pi Pico board footprint 3D visual

If not already open, open the the footprint editor

symbol library manager

double click on the `RPi_Pico_SMD_TH` footprint from the `MCU_RaspberriPi_and_Boards` library and then click on the `Footprint properties` icon:



In the footprint properties window, first select the `3D Settings` tab. Please note that the preview shows only the PCB board with the footprint added on step 3, without any 3D representation of the Raspberry Pi Pico board. Now click on the folder icon to add the 3D model:



Navigate to the `RP-Pico Libraries` folder, select the `Pico.wrl` file and wait until the model is shown in the right panel, then confirm with OK:



The model is already scaled and translated to match the footprint:



now close the `Footprint Properties` window, and the `Footprint Editor`, obviously saving the changes.

## Conclusion

Now that you've installed the schema and footprint and added the 3D model to the footprint, you can use the Raspberry Pi Pico board on your KiCad projects.

I've also added a test KiCad Project on the `Test` folder, that you can use to see an example of it.

Have fun!

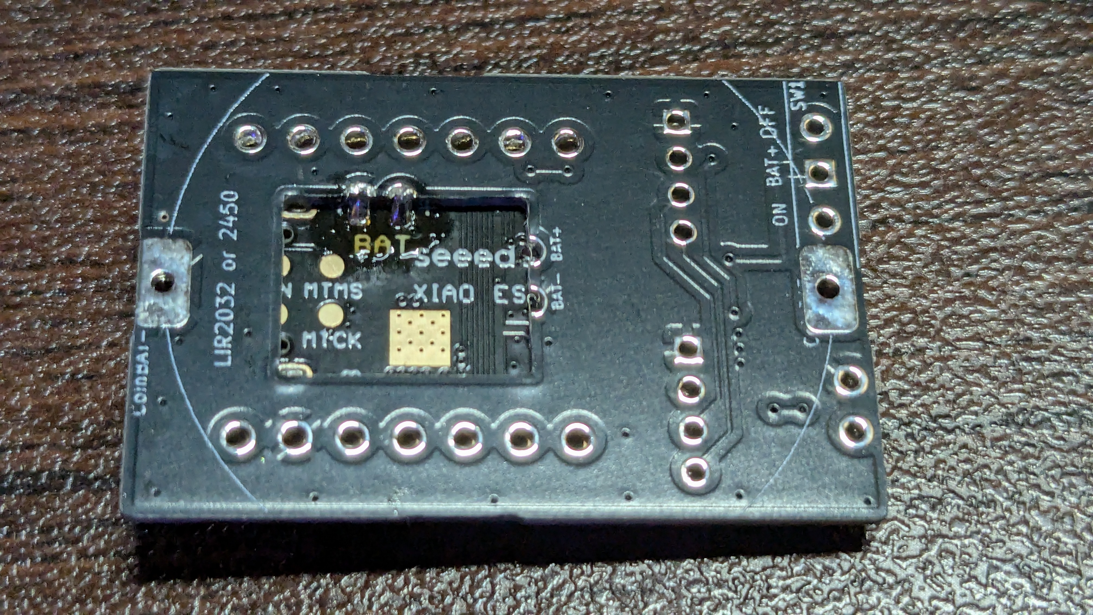
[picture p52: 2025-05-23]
img/XIAO_Castlated-Hole_Soldered.jpg

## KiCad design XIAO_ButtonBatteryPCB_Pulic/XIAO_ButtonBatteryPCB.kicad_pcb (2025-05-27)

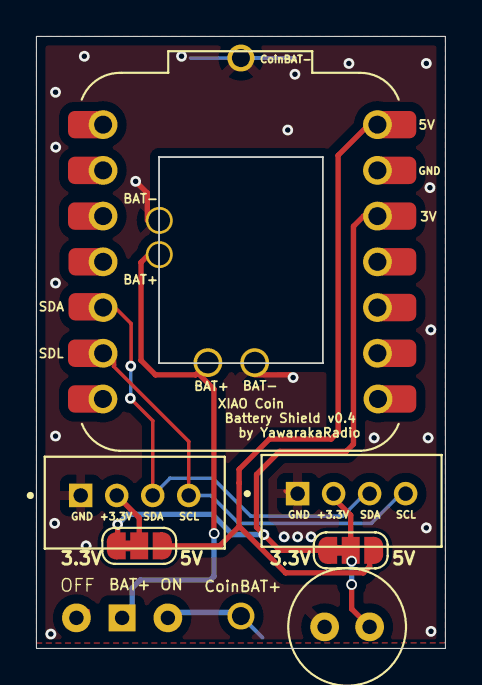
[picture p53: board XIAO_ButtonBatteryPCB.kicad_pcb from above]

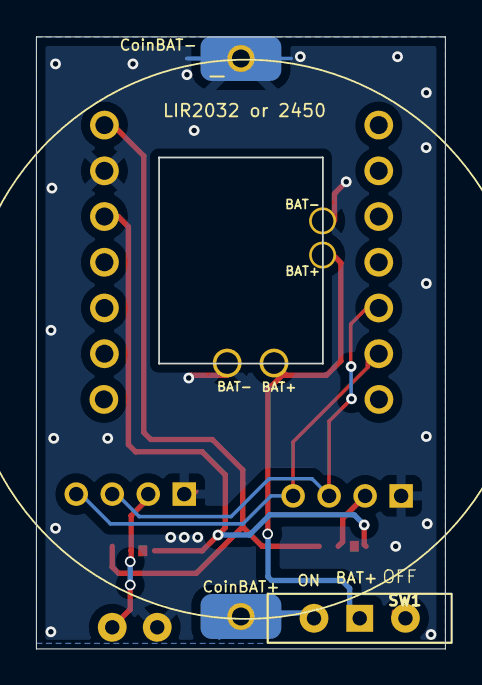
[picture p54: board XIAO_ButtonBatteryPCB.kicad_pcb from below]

Board: 2 copper layers, 22.7 x 34.0 mm, 8 parts (2 on the bottom side), 8 nets.

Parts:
C1: C; C_Radial_D6.3mm_H7.0mm_P2.50mm
C4: C; 2450_MYOUNG BS-24-B4AK014
J1, J2: 110990030__Grove; SEEED_110990030
JP1, JP2: SolderJumper_3_Bridged12; SolderJumper-3_P1.3mm_Bridged12_RoundedPad1.0x1.5mm_NumberL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
SW1: MK-12D13G4-B; SW_Slide-03_Wuerth-WS-SLTV_10x2.5x6.4_P2.54mm
U1: XIAO-ESP32C3_C6; XIAO_Seeed_ESP32C3_C6_BatteryHolder_v2.1

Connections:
/+3.3V: JP1.1 (A), JP2.1 (A), U1.12 (3V3)
/+5V: JP1.3 (B), JP2.3 (B), U1.14 (5V)
/Grove1_Vcc: C1.2, J1.2 (Vcc), JP1.2 (C)
/Grove2_Vcc: J2.2 (Vcc), JP2.2 (C)
/SCL: J1.4 (SCL), J2.4 (SCL), U1.6 (PA9_A5_D5_SCL)
/SDA: J1.3 (SDA), J2.3 (SDA), U1.5 (PA8_A4_D4_SDA)
GND: C1.1, C4.2, J1.1 (GND), J2.1 (GND), U1.13 (GND), U1.16 (Vbat-), U1.27 (Vbat-)
unnamed: SW1.1 (B), U1.17 (Vbat+), U1.26 (Vbat+)

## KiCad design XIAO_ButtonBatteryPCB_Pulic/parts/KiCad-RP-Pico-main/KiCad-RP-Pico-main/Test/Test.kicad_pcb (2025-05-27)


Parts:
J1, J2: Conn_01x20; PinSocket_1x20_P1.00mm_Vertical
J3: Conn_01x03; PinSocket_1x03_P1.00mm_Vertical
U1: Pico; RPi_Pico_SMD_TH

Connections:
GND: J1.3, J1.8, J1.13, J1.18, J2.3, J2.13, J2.18, J3.2, U1.3 (GND), U1.8 (GND), U1.13 (GND), U1.18 (GND), U1.23 (GND), U1.28 (GND), U1.38 (GND), U1.42 (GND)
unnamed: J1.1, U1.1 (GPIO0)
unnamed: J1.2, U1.2 (GPIO1)
unnamed: J1.4, U1.4 (GPIO2)
unnamed: J1.5, U1.5 (GPIO3)
unnamed: J1.6, U1.6 (GPIO4)
unnamed: J1.7, U1.7 (GPIO5)
unnamed: J1.9, U1.9 (GPIO6)
unnamed: J1.10, U1.10 (GPIO7)
unnamed: J1.11, U1.11 (GPIO8)
unnamed: J1.12, U1.12 (GPIO9)
unnamed: J1.14, U1.14 (GPIO10)
unnamed: J1.15, U1.15 (GPIO11)
unnamed: J1.16, U1.16 (GPIO12)
unnamed: J1.17, U1.17 (GPIO13)
unnamed: J1.19, U1.19 (GPIO14)
unnamed: J1.20, U1.20 (GPIO15)
unnamed: J2.1, U1.40 (VBUS)
unnamed: J2.2, U1.39 (VSYS)
unnamed: J2.4, U1.37 (3V3_EN)
unnamed: J2.5, U1.36 (3V3)
unnamed: J2.6, U1.35 (ADC_VREF)
unnamed: J2.7, U1.34 (GPIO28_ADC2)
unnamed: J2.8, U1.33 (AGND)
unnamed: J2.9, U1.32 (GPIO27_ADC1)
unnamed: J2.10, U1.31 (GPIO26_ADC0)
unnamed: J2.11, U1.30 (RUN)
unnamed: J2.12, U1.29 (GPIO22)
unnamed: J2.14, U1.27 (GPIO21)
unnamed: J2.15, U1.26 (GPIO20)
unnamed: J2.16, U1.25 (GPIO19)
unnamed: J2.17, U1.24 (GPIO18)
unnamed: J2.19, U1.22 (GPIO17)
unnamed: J2.20, U1.21 (GPIO16)
unnamed: J3.1, U1.43 (SWDIO)
unnamed: J3.3, U1.41 (SWCLK)


Board: 2 copper layers, 43.0 x 65.0 mm, 4 parts (0 on the bottom side), 36 nets.

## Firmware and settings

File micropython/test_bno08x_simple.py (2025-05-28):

# BNO08x Micropython I2C Test program - Simplified version
# Basic sensor data display only

from machine import I2C, Pin
from utime import sleep_ms
from bno08x import *

# I2Cピン設定（ESP32モデル別）
I2C1_SDA = Pin(5)  # XIAO-ESP32 S3:5, C6:22, C3:6
I2C1_SCL = Pin(6)  # XIAO-ESP32 S3:6, C6:23, C3:7

# I2C初期化
i2c1 = I2C(0, scl=I2C1_SCL, sda=I2C1_SDA, freq=400000, timeout=200000)

# BNO085センサー初期化
bno = BNO08X(i2c1, debug=False)
print("BNO08x I2C connection : Done\n")

# センサー機能を有効化
bno.enable_feature(BNO_REPORT_ACCELEROMETER, 50)        # 加速度センサー 50ms間隔
bno.enable_feature(BNO_REPORT_GYROSCOPE, 50)            # ジャイロスコープ 50ms間隔
bno.enable_feature(BNO_REPORT_GAME_ROTATION_VECTOR, 50) # ゲーム回転ベクトル 50ms間隔
bno.enable_feature(BNO_REPORT_GRAVITY, 50)              # 重力ベクトル 50ms間隔

# オイラー角とクォータニオンの設定
bno.set_quaternion_euler_vector(BNO_REPORT_GAME_ROTATION_VECTOR)

print("BNO08x sensors enabling : Done\n")
print("Starting sensor data display in 3 seconds...")
sleep_ms(3000)

# 初期キャリブレーション
bno.calibration()
print("Initial sensor calibration complete")
sleep_ms(1000)

# 姿勢の零点調整
bno.tare()
print("Tare operation complete - current orientation set as reference")
sleep_ms(1000)

print("\n===== Starting sensor data display =====\n")

# メインループ
count = 0
while True:
    count += 1
    
    print(f"===== Sensor Data Update #{count} =====")
    
    # 加速度データ（重力込み）
    accel_x, accel_y, accel_z = bno.acc
    print(f"Acceleration\tX: {accel_x:+.3f}\tY: {accel_y:+.3f}\tZ: {accel_z:+.3f}\tm/s²")
    
    # 重力ベクトル
    grav_x, grav_y, grav_z = bno.gravity
    print(f"Gravity\t\tX: {grav_x:+.3f}\tY: {grav_y:+.3f}\tZ: {grav_z:+.3f}\tm/s²")
    
    # 線形加速度（重力補正済み）
    linear_x = accel_x - grav_x
    linear_y = accel_y - grav_y
    linear_z = accel_z - grav_z
    print(f"Linear Accel\tX: {linear_x:+.3f}\tY: {linear_y:+.3f}\tZ: {linear_z:+.3f}\tm/s²")
    
    # ジャイロスコープ（角速度）
    gyro_x, gyro_y, gyro_z = bno.gyro
    print(f"Gyroscope\tX: {gyro_x:+.3f}\tY: {gyro_y:+.3f}\tZ: {gyro_z:+.3f}\trad/s")
    
    # オイラー角（Roll, Pitch, Yaw）
    roll, pitch, yaw = bno.euler
    print(f"Euler Angle\tRoll: {roll:+.3f}\tPitch: {pitch:+.3f}\tYaw: {yaw:+.3f}\trad")
    
    # クォータニオン
    quat_w, quat_x, quat_y, quat_z = bno.quaternion
    print(f"Quaternion\tW: {quat_w:+.3f}\tX: {quat_x:+.3f}\tY: {quat_y:+.3f}\tZ: {quat_z:+.3f}")
    
    print()  # 空行
    
    # 1秒間隔で表示
    sleep_ms(1000) 



'''    
===== Sensor Data Update #42 =====
Acceleration	X: -3.016	Y: -8.043	Z: -4.281	m/s²
Gravity		X: -3.023	Y: -8.047	Z: -4.281	m/s²
Linear Accel	X: +0.008	Y: +0.004	Z: +0.000	m/s²
Gyroscope	X: +0.008	Y: -0.008	Z: +0.008	rad/s
Euler Angle	Roll: -118.298	Pitch: +18.422	Yaw: -33.818	rad
Quaternion	W: -0.787	X: +0.325	Y: -0.016	Z: +0.524

'''

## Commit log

2025-05-27 add XIAO PCB
    [1-2834016-4.step, 10-Pin Header - Male - 2.54mm.step, 11-Pin Header - Male - 2.54mm.step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]
2025-05-27 まだできない
2025-05-28 add 代替電源スイッチ
2025-07-03 Castellated Holes = No
